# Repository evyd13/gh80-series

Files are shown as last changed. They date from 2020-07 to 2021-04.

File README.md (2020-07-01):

# GH80 series keyboard PCBs for Cherry boards

Please read the license before use. Each board has its own BOM and gerber files included.

These boards have been tested by numerous people, but I cannot guarantee that they work for your board.

I will not help you when you fuck up your soldering work, lol (though I might because I'm just too kind)

Oh by the way, use kicad nightly to open the source files.

## GH80-3000 vs GH80-3003
The 3000 is made by someone else, and the 3003 is mine. See it as my take on the same idea.

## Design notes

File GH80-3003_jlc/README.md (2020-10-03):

# GH80-3003 jlc

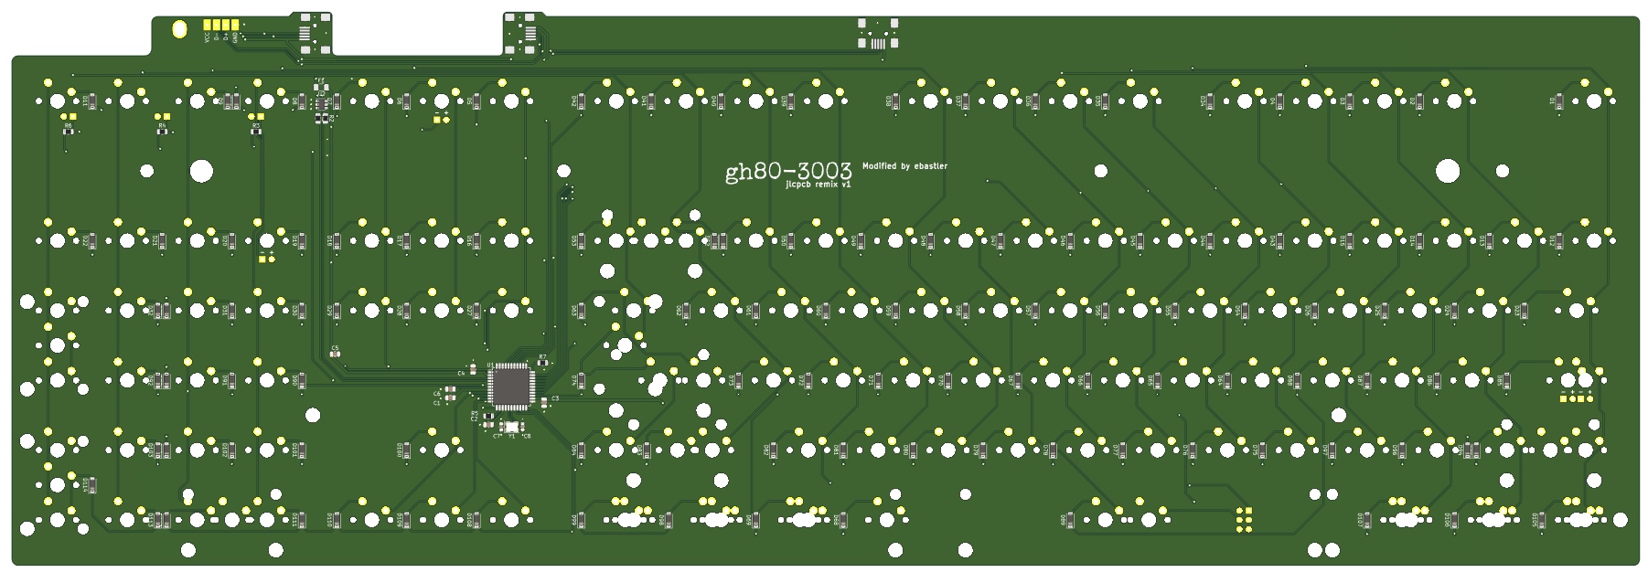
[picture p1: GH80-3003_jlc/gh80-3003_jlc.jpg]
GH80-3003 PCB


PCB designed by evyd13, edited to be assembled at jlcpcb by ebastler

Gerber, BOM and CPL file for jlcpcb assembly are included. They have been tested and confirmed working, but I can not guarantee that jlcpcb will not make any breaking changes. jlcpcb stocks might change, parts could go EOL. Compare MCU/diode/SRV05 rotation before ordering, to be sure.

If you order a small batch and sell the unneeded ones, please keep the license in mind.

## jlcpcb components (already in BOM/assembly files)

| Reference  | jlcpcb part # | Description | Value | Package  | Amount |
| --- | --- | --- | --- | --- | ---:|
| C1-C4 | C49678 | Capacitor | 0.1 uF | 0805 | 4 |
| C5 | C1779 | Capacitor | 4.7 uF | 0805 | 1 |
| C6 | C28323 | Capacitor | 1 uF | 0805 | 1 |
| C7, C8 | C1653 | Capacitor | 22 pF | 0603 | 2 |
| D1-D114 | C81598 | Diode | 1N4148 | SOD-123  | 114 |
| F1 | C183290 | Fuse | 750 mA | 1206 | 1 |
| R1, R2 | C17561 | Resistor | 22 | 0805 | 2 |
| R3, R4, R6 | C17513 | Resistor | 1 k | 0805 | 3 |
| R5, R6 | C17414 | Resistor | 10 k | 0805 | 2 |
| U1 | C44854 | MCU | 32U4 | QFP-44 | 1 |
| U2 | C85364 | ESD Protection | SRV-05 | SOT-23-6 | 1 |
| Y1 | C13738 | Crystal | 16 MHz | 3225-4 | 1 |

## Other parts
| Reference  | LCSC part # | Description | Value | Package  | Amount  |
| --- | --- | --- | --- | --- | ---:|
| K1-K114 | | Keyswitch | | MX-like  | depends |
| L1-L3 | | LED | | 3 mm THT | 3 |
| J2-J4 | C105424 | Connector | mini USB | SMD | 3 |
| SW1 | C92584 | Pushbutton | | SMD | 1 |

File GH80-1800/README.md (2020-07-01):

# GH80-1800

GH80-1800 PCB

## BOM

| LCSC part # | Description | Value | Package  | Amount |
| --- | --- | ----- | --- | ---:|
| C128353 | Capacitor | 0.1uF | 0805 | 4 |
| C131056 | Capacitor | 4.7uF | 0805 | 1 |
| C215803 | Capacitor | 1uF | 0805 | 1 |
| C109001 | Diode | | 0805 | 108 |
| C105424 | Connector | | SMD | 3 |
| C103904 | Resistor | 10K | 0805 | 2 |
| C384174 | Resistor | 1K | 0805 | 3 |
| C325772 | Resistor | 22 | 0805 | 2 |
| C44854 | MCU | 32U4  | QFP-44 | 1 |
| C341521 | Resonator | 16MHz | SMD | 1 |
| C92584 | Switch | | SMD | 1 |

Use at your own risk.

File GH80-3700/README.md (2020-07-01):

# GH80-3700

GH80-3700 PCB

## BOM main pcb

| LCSC part # | Description | Value | Package  | Amount |
| --- | --- | ----- | --- | ---:|
| C128353 | Capacitor | 0.1uF | 0805 | 4 |
| C131056 | Capacitor | 4.7uF | 0805 | 1 |
| C215803 | Capacitor | 1uF | 0805 | 1 |
| C109001 | Diode | | 0805 | 24 |
| C165948 | Connector | | SMD/THT  | 1 |
| C103904 | Resistor | 10K | 0805 | 2 |
| C212411 | Resistor | 5.1K  | 0805 | 2 |
| C384174 | Resistor | 1K | 0805 | 5 |
| C325772 | Resistor | 22 | 0805 | 2 |
| C44854 | MCU | 32U4  | QFP-44 | 1 |
| C7519 | ESD chip | | SOT23-6  | 1 |
| C261942 | Fuse | | 0805 | 1 |
| C341521 | Resonator | 16MHz | SMD | 1 |
| C223806 | Switch | | THT | 1 |

## BOM daughterboard (speaker and ps/2 port) pcb

It's a little expansion board to be able to use a speaker or PS/2 mouse, or just to fill up that hole in the case.

| LCSC part # | Description | Value | Package  | Amount |
| --- | --- | ----- | --- | ---:|
| C131056 | Capacitor | 4.7uF | 0805 | 1 |
| C17673 | Resistor | 4.7K  | 0805 | 2 |
| C261942 | Fuse | | 0805 | 1 |
| C136657 | JST SH 5 pin  | | SMD | 2 |
|  C77848 | PS2 connector | | THT | 1 |

You'll also need a JST SH 5 pin cable for this one. Those can be found on aliexpress or similar sites.

Use at your own risk.

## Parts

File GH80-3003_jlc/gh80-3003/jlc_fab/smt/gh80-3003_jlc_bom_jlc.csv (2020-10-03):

Comment | Designator | Footprint | LCSC Part #
0.1u | C1,C2,C3,C4 | C_0805_2012Metric | C49678
4.7u | C5 | C_0805_2012Metric | C1779
1u | C6 | C_0805_2012Metric | C28323
22p | C7,C8 | C_0603_1608Metric | C1653
1N4148 | D1,D2,D3,D4,D5,D6,D7,D8,D9,D10,D11,D12,D13,D14,D15,D16,D17,D18,D19,D20,D21,D22,D23,D24,D25,D26,D27,D28,D29,D30,D31,D32,D33,D34,D35,D36,D37,D38,D39,D40,D41,D42,D43,D44,D45,D46,D47,D48,D49,D50,D51,D52,D53,D54,D55,D56,D57,D58,D59,D60,D61,D62,D63,D64,D65,D66,D67,D68,D69,D70,D71,D72,D73,D74,D75,D76,D77,D78,D79,D80,D81,D82,D83,D84,D85,D86,D87,D88,D89,D90,D91,D92,D93,D94,D95,D96,D97,D98,D99,D100,D101,D102,D103,D104,D105,D106,D107,D108,D109,D110,D111,D112,D113,D114 | D_SOD-123 | C81598
Fuse | F1 | Fuse_1206_3216Metric | C183290
22 | R1,R2 | R_0805_2012Metric | C17561
1k | R3,R4,R6 | R_0805_2012Metric | C17513
10k | R5,R7 | R_0805_2012Metric | C17414
ATmega32U4 | U1 | TQFP-44_10x10mm_P0.8mm | C44854
SRV05-4 | U2 | SOT-23-6 | C85364
Crystal_GND24_Small | Y1 | Crystal_SMD_3225-4Pin_3.2x2.5mm | C13738

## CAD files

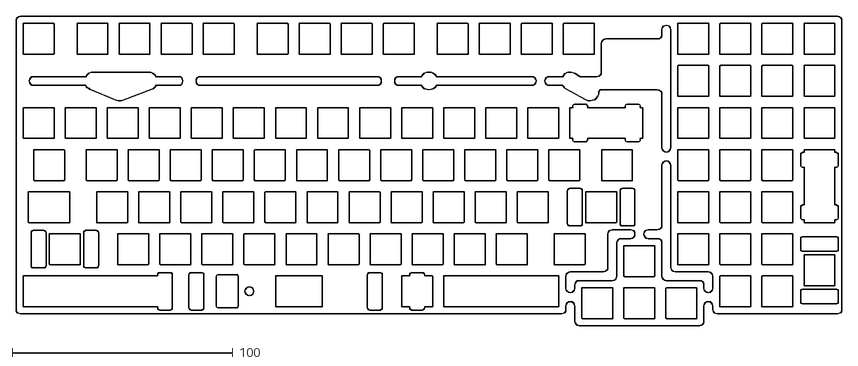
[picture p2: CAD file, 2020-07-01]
GH80-1800/plate/gh80_1800_ANSI.dxf
374.0 x 140.1

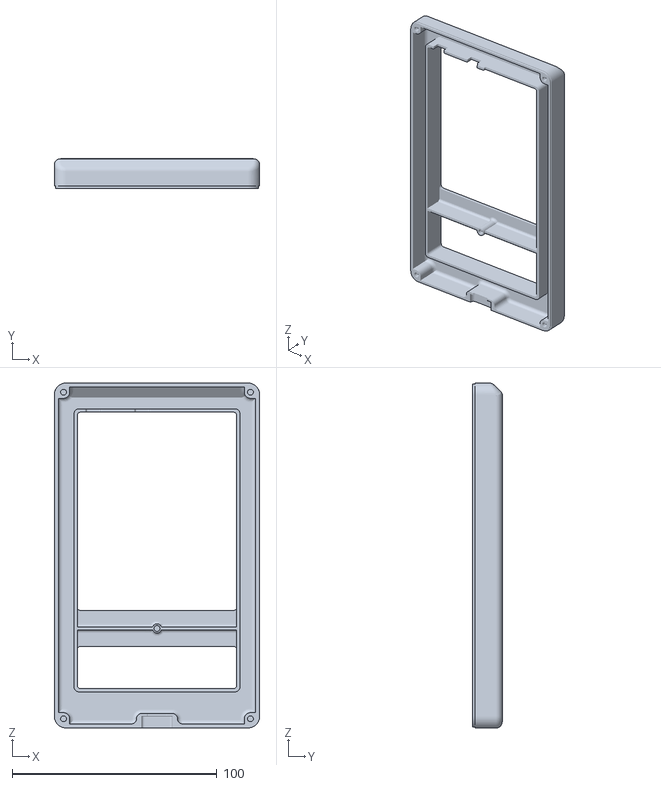
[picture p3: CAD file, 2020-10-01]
GH80-3700/case/top.stl
100.2 x 14.4 x 168.4

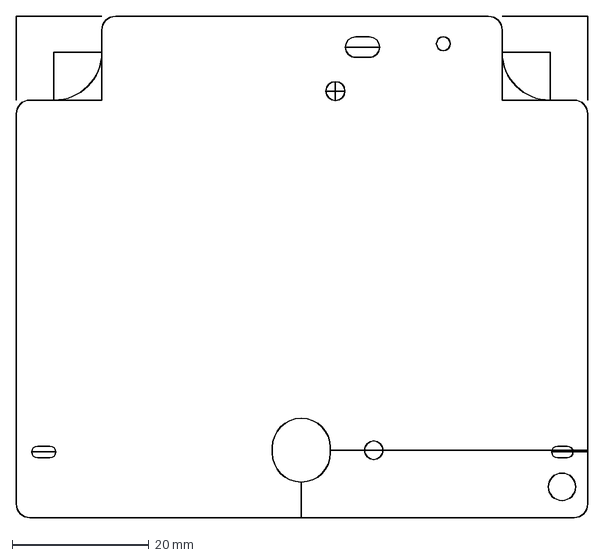
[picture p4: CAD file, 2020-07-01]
GH80-3700/daughterboard/pcb.dxf
83.5 x 73.3 mm

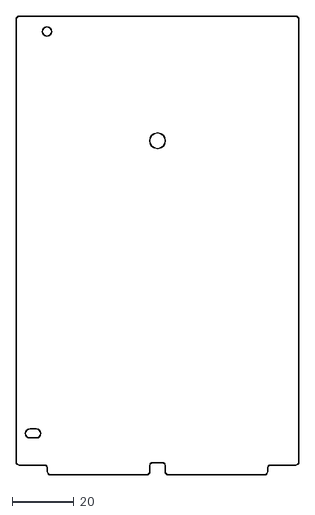
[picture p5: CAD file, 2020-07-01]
GH80-3700/PCB/pcb.dxf
91.8 x 149.1

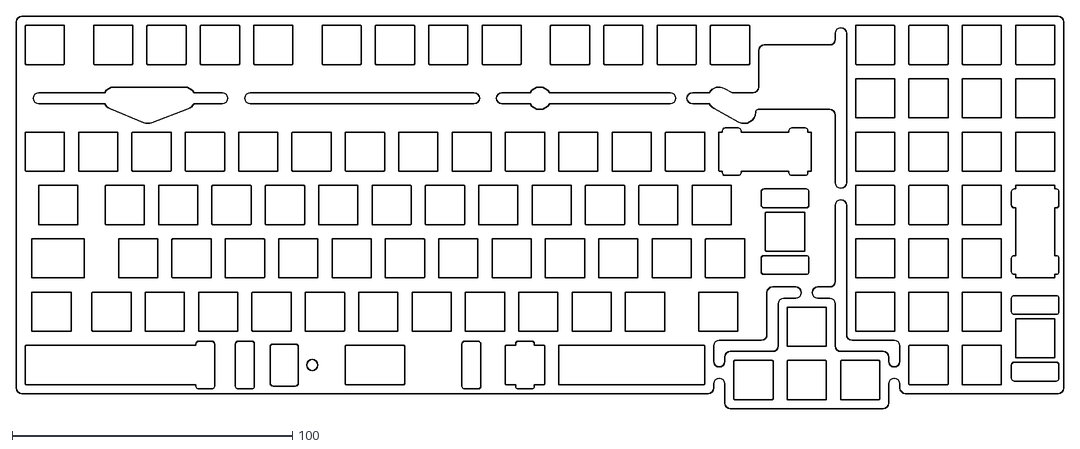
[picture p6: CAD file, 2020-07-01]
GH80-1800/plate/gh80_1800_ISO.dxf
374.0 x 140.1

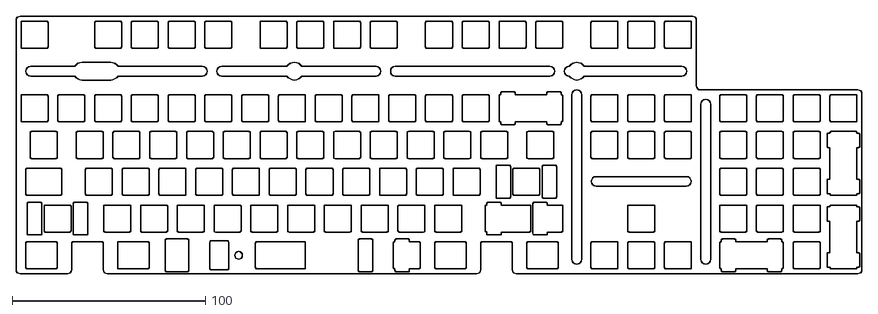
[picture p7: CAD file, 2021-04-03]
GH80-3003/plate/gh80-3003-ansi.dxf
438.2 x 133.4

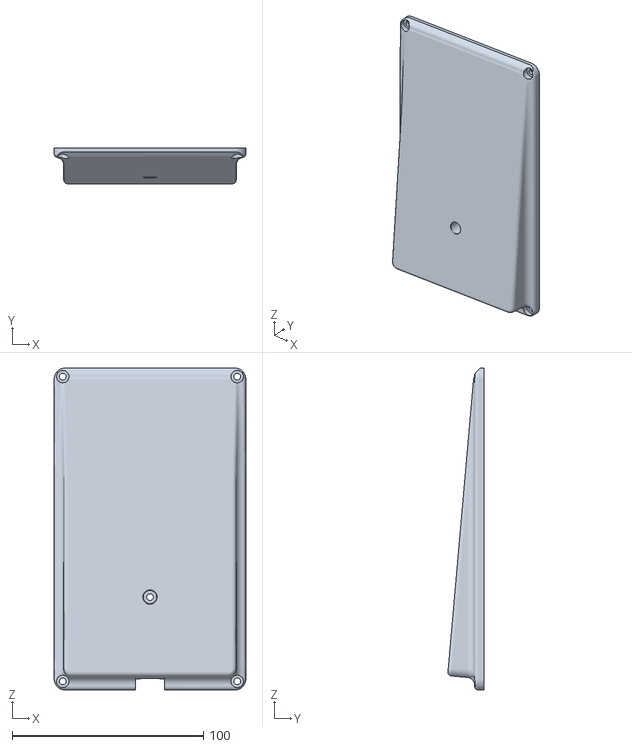
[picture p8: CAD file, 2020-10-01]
GH80-3700/case/bottom.stl
100.2 x 18.9 x 168.4

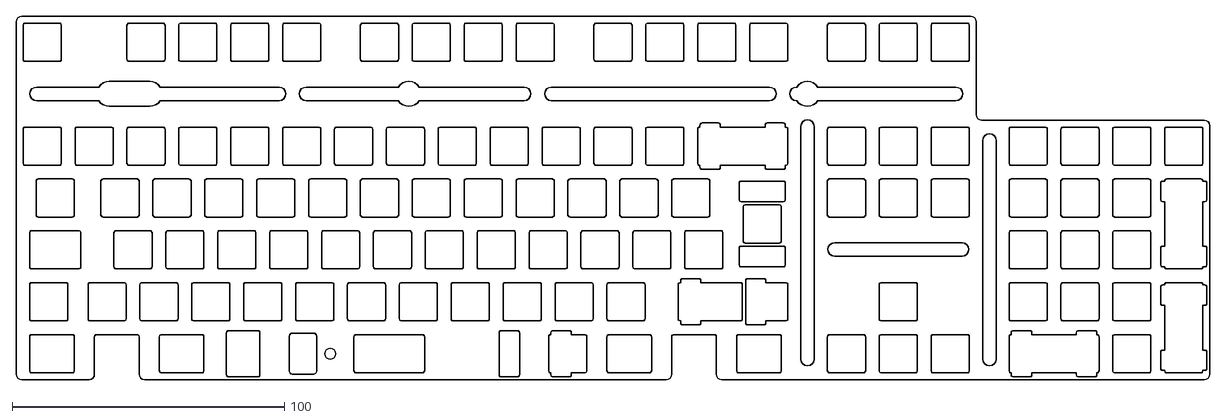
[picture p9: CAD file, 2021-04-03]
GH80-3003/plate/gh80-3003-iso.dxf
438.2 x 133.4

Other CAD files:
GH80-3003/plate/plate.FCStd
GH80-3700/plate/G80-3700.FCStd
GH80-1800/plate/gh80_1800.FCStd
GH80-3700/case/case.f3z
GH80-3700/plate/G80-3700.dxf

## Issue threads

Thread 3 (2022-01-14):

1800 in kicad does not seem to open properly

alinelena, 2022-01-14:
I am opening 1800 in kicad but seems does not open quite right.
https://i.imgur.com/adBBMC9.png
if I click on them footprints are not there.

supplied gerbers or generated gerbers do not seem to load on jlcpcb either.

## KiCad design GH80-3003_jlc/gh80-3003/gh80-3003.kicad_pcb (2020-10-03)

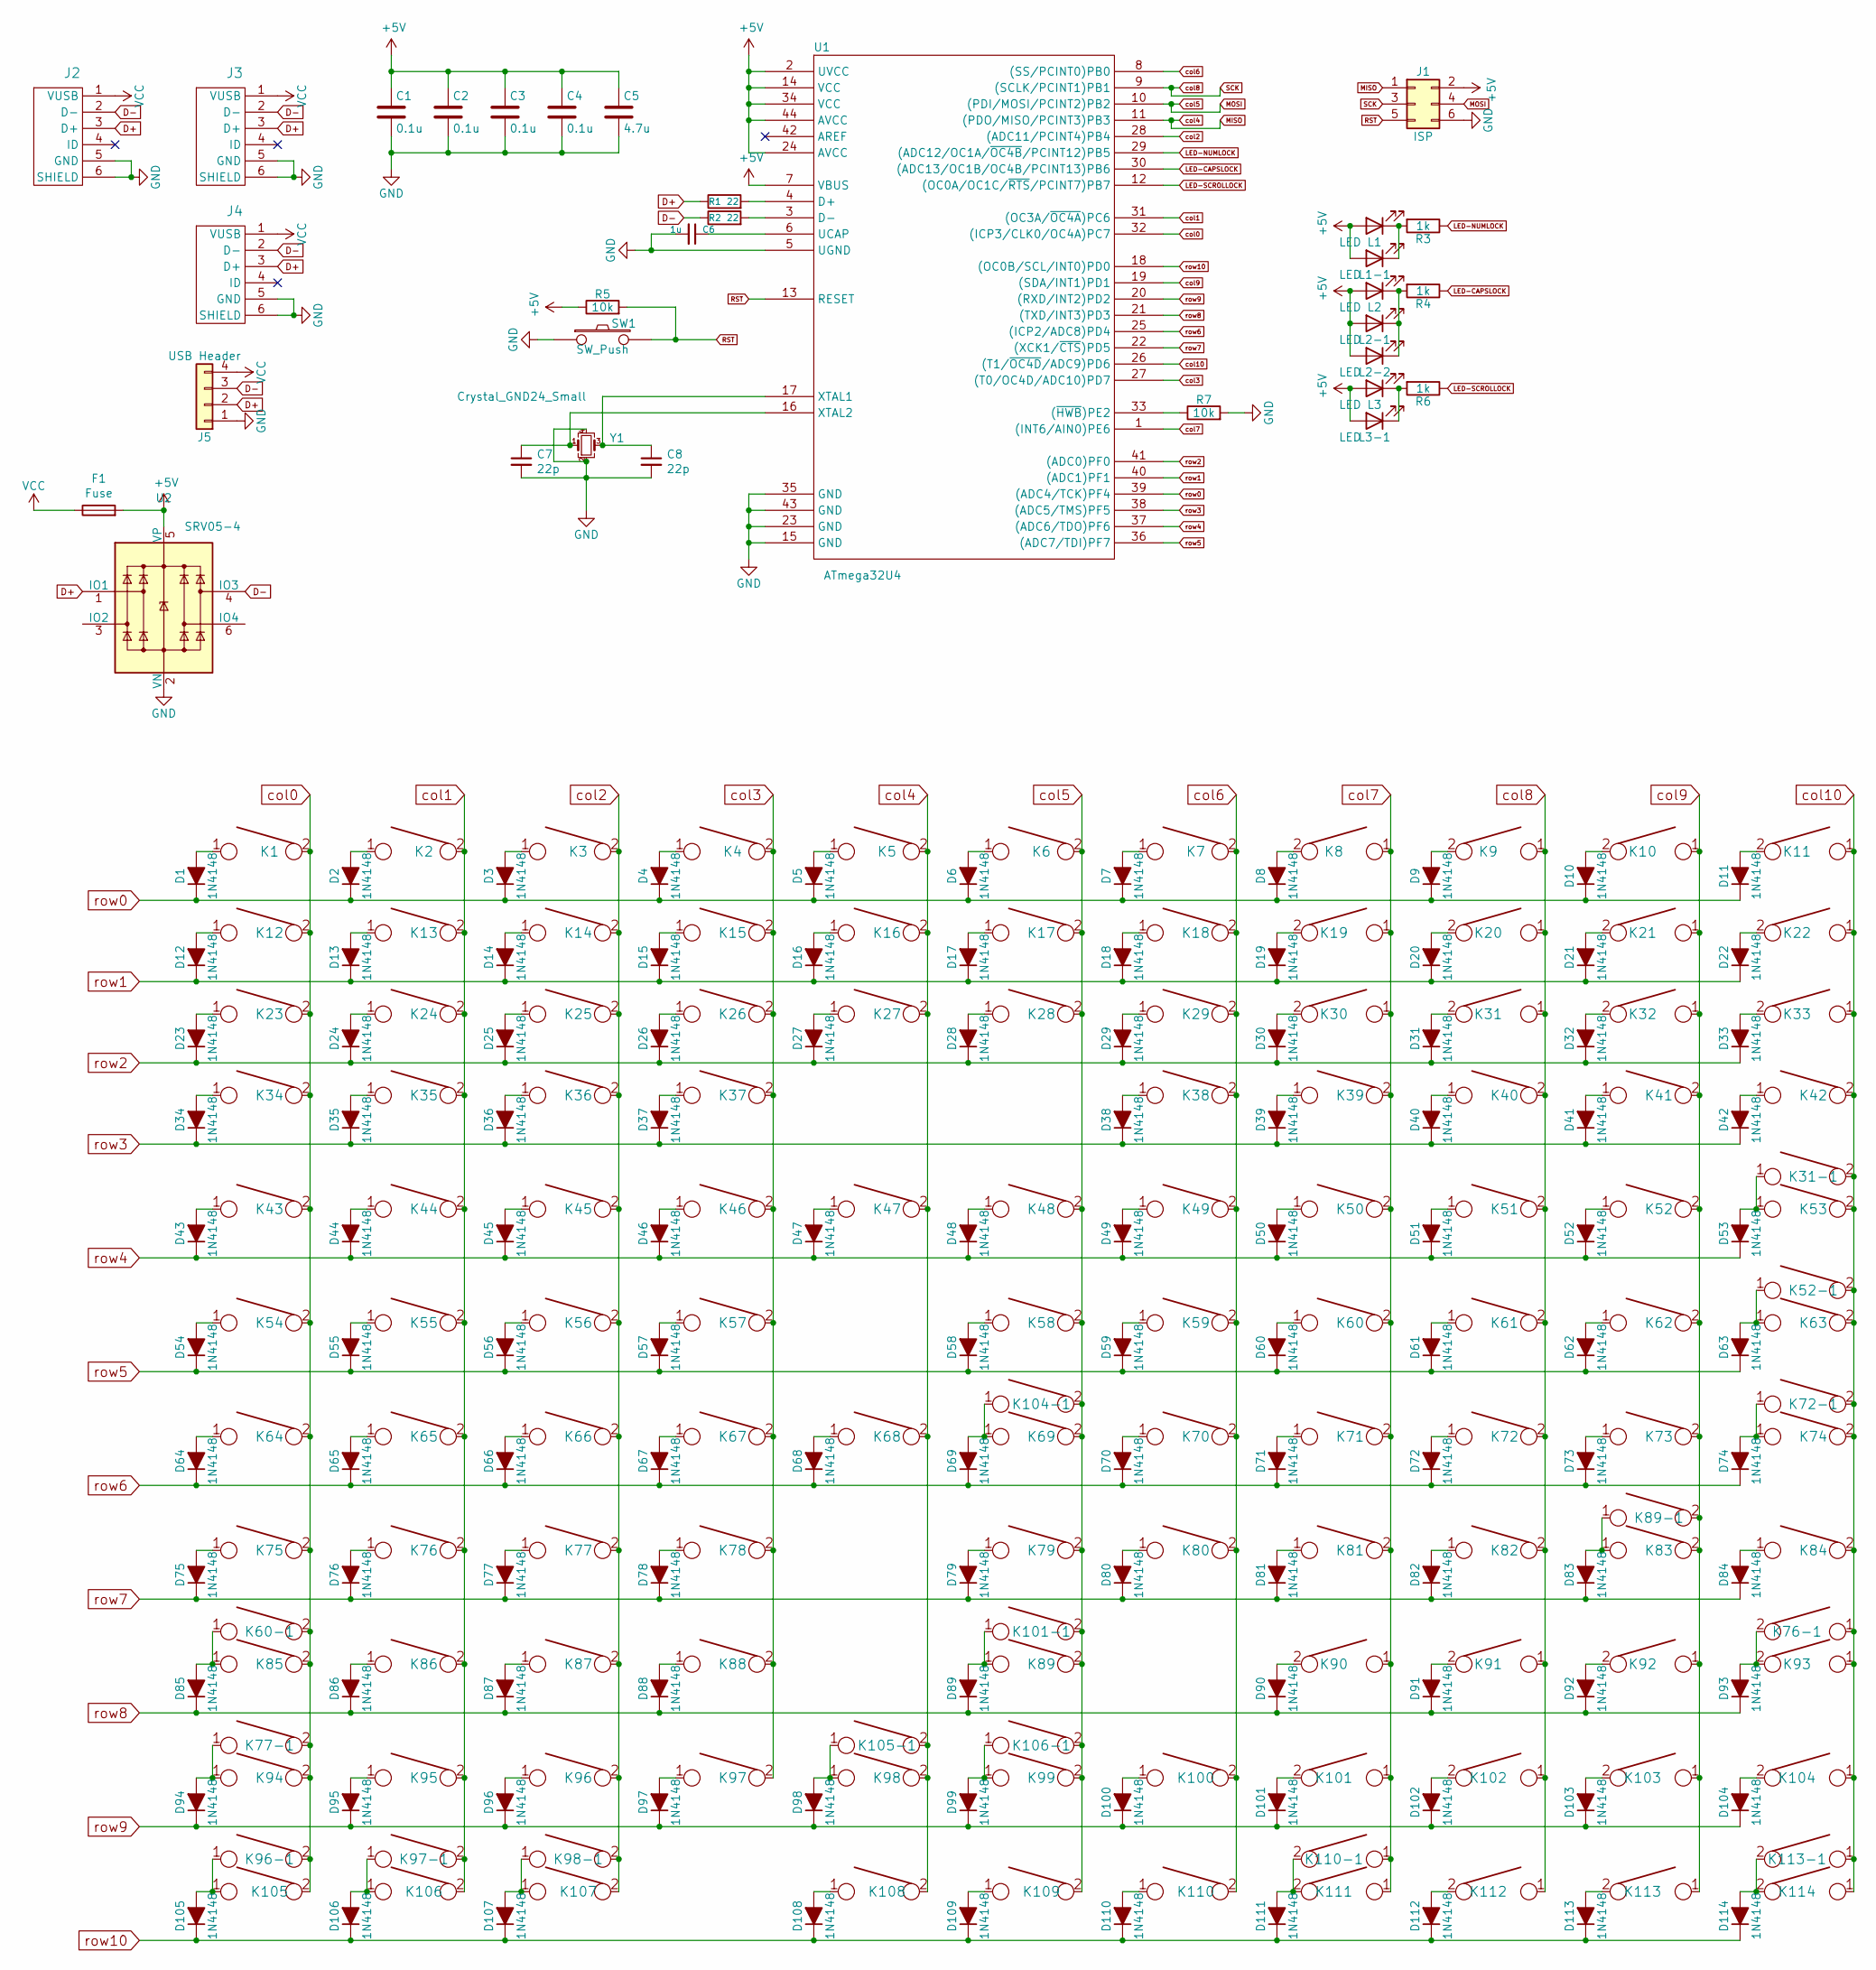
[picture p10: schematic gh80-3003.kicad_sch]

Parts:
C1, C2, C3, C4: 0.1u; C_0805_2012Metric; LCSC C49678
C5: 4.7u; C_0805_2012Metric; LCSC C1779
C6: 1u; C_0805_2012Metric; LCSC C28323
C7, C8: 22p; C_0603_1608Metric; LCSC C1653
D1, D2, D3, D4, D5, D6, D7, D8, D9, D10, D11, D12, D13, D14, D15, D16, D17, D18, D19, D20, D21, D22, D23, D24, D25, D26, D27, D28, D29, D30, D31, D32, D33, D34, D35, D36, D37, D38, D39, D40, D41, D42, D43, D44, D45, D46, D47, D48, D49, D50, D51, D52, D53, D54, D55, D56, D57, D58, D59, D60, D61, D62, D63, D64, D65, D66, D67, D68, D69, D70, D71, D72, D73, D74, D75, D76, D77, D78, D79, D80, D81, D82, D83, D84, D85, D86, D87, D88, D89, D90, D91, D92, D93, D94, D95, D96, D97, D98, D99, D100, D101, D102, D103, D104, D105, D106, D107, D108, D109, D110, D111, D112, D113, D114: 1N4148; D_SOD-123; LCSC C81598
F1: Fuse; Fuse_1206_3216Metric; LCSC C183290
J1: ISP; isp_standard
J2, J3, J4: USB_mini_micro_B; USB_Mini_SMD
J5: USB Header; USB_breakout
K1, K2, K3, K4, K5, K6, K7, K8, K9, K10, K11, K12, K13, K14, K15, K16, K17, K18, K19, K20, K21, K22, K24, K25, K26, K27, K28, K29, K30, K31, K31-1, K32, K33, K34, K35, K36, K37, K38, K39, K40, K41, K42, K43, K44, K45, K46, K47, K48, K49, K50, K51, K52, K52-1, K54, K55, K56, K57, K58, K59, K60, K61, K62, K64, K65, K66, K67, K70, K71, K72, K73, K75, K76, K76-1, K77, K78, K79, K80, K81, K82, K84, K86, K87, K88, K90, K91, K92, K95, K96, K97, K98, K100, K101, K102, K103, K104, K106, K108, K109, K110, K110-1, K112, K113, K113-1: KEYSW; CHERRY_PLATE_100H
K23, K63, K69, K99, K105, K107: KEYSW; CHERRY_PLATE_150H
K53, K111: KEYSW; CHERRY_PCB_200H
K60-1, K68, K77-1, K96-1, K97-1, K98-1, K104-1, K105-1, K106-1: KEYSW; CHERRY_PLATE_125H
K72-1: KEYSW; CHERRY_PCB_200H_V
K74, K94: KEYSW; CHERRY_PCB_225H
K83: KEYSW; CHERRY_PCB_275H
K85, K89-1: KEYSW; CHERRY_PLATE_175H
K89: KEYSW; CHERRY_PCB_700H
K93, K114: KEYSW; CHERRY_PCB_200H_V_F
K101-1: KEYSW; CHERRY_PCB_625H
L1, L2, L3: LED; LED_D3.0mm
L1-1, L2-1, L2-2, L3-1: LED; CHERRY_MX_LED
R1, R2: 22; R_0805_2012Metric; LCSC C17561
R3, R4, R6: 1k; R_0805_2012Metric; LCSC C17513
R5, R7: 10k; R_0805_2012Metric; LCSC C17414
SW1: SW_Push; SW_SPST_TL3342
U1: ATmega32U4; TQFP-44_10x10mm_P0.8mm; LCSC C44854
U2: SRV05-4; SOT-23-6; LCSC C85364
Y1: Crystal_GND24_Small; Crystal_SMD_3225-4Pin_3.2x2.5mm; LCSC C13738

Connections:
+5V: C1.1, C2.1, C3.1, C4.1, C5.1, F1.2, J1.2, L1.2 (A), L1-1.2 (A), L2.2 (A), L2-1.2 (A), L2-2.2 (A), L3.2 (A), L3-1.2 (A), R5.1, U1.2 (UVCC), U1.7 (VBUS), U1.14 (VCC), U1.24 (AVCC), U1.34 (VCC), U1.44 (AVCC), U2.5 (VP)
D+: J2.3 (D+), J3.3 (D+), J4.3 (D+), J5.2, R1.1, U2.1 (IO1)
D-: J2.2 (D-), J3.2 (D-), J4.2 (D-), J5.3, R2.1, U2.4 (IO3)
GND: C1.2, C2.2, C3.2, C4.2, C5.2, C6.2, C7.2, C8.2, J1.6, J2.5 (GND), J2.6 (SHIELD), J3.5 (GND), J3.6 (SHIELD), J4.5 (GND), J4.6 (SHIELD), J5.1, R7.2, SW1.1, U1.5 (UGND), U1.15 (GND), U1.23 (GND), U1.35 (GND), U1.43 (GND), U2.2 (VN), Y1.2, Y1.4
LED-CAPSLOCK: R4.1, U1.30 ((ADC13/OC1B/OC4B/PCINT13)PB6)
LED-NUMLOCK: R3.1, U1.29 ((ADC12/OC1A/~OC4B~/PCINT12)PB5)
LED-SCROLLOCK: R6.1, U1.12 ((OC0A/OC1C/~RTS~/PCINT7)PB7)
MISO: J1.1, K5.2, K16.2, K27.2, K47.2, K68.2, K98.2, K105-1.2, K108.2, U1.11 ((PDO/MISO/PCINT3)PB3)
MOSI: J1.4, K6.2, K17.2, K28.2, K48.2, K58.2, K69.2, K79.2, K89.2, K99.2, K101-1.2, K104-1.2, K106-1.2, K109.2, U1.10 ((PDI/MOSI/PCINT2)PB2)
unnamed: C6.1, U1.6 (UCAP)
unnamed: C7.1, U1.16 (XTAL2), Y1.1
unnamed: C8.1, U1.17 (XTAL1), Y1.3
unnamed: D1.2 (A), K1.1
unnamed: D2.2 (A), K2.1
unnamed: D3.2 (A), K3.1
unnamed: D4.2 (A), K4.1
unnamed: D5.2 (A), K5.1
unnamed: D6.2 (A), K6.1
unnamed: D7.2 (A), K7.1
unnamed: D8.2 (A), K8.2
unnamed: D9.2 (A), K9.2
unnamed: D10.2 (A), K10.2
unnamed: D11.2 (A), K11.2
unnamed: D12.2 (A), K12.1
unnamed: D13.2 (A), K13.1
unnamed: D14.2 (A), K14.1
unnamed: D15.2 (A), K15.1
unnamed: D16.2 (A), K16.1
unnamed: D17.2 (A), K17.1
unnamed: D18.2 (A), K18.1
unnamed: D19.2 (A), K19.2
unnamed: D20.2 (A), K20.2
unnamed: D21.2 (A), K21.2
unnamed: D22.2 (A), K22.2
unnamed: D23.2 (A), K23.1
unnamed: D24.2 (A), K24.1
unnamed: D25.2 (A), K25.1
unnamed: D26.2 (A), K26.1
unnamed: D27.2 (A), K27.1
unnamed: D28.2 (A), K28.1
unnamed: D29.2 (A), K29.1
unnamed: D30.2 (A), K30.2
unnamed: D31.2 (A), K31.2
unnamed: D32.2 (A), K32.2
unnamed: D33.2 (A), K33.2
unnamed: D34.2 (A), K34.1
unnamed: D35.2 (A), K35.1
unnamed: D36.2 (A), K36.1
unnamed: D37.2 (A), K37.1
unnamed: D38.2 (A), K38.1
unnamed: D39.2 (A), K39.1
unnamed: D40.2 (A), K40.1
unnamed: D41.2 (A), K41.1
unnamed: D42.2 (A), K42.1
unnamed: D43.2 (A), K43.1
unnamed: D44.2 (A), K44.1
unnamed: D45.2 (A), K45.1
unnamed: D46.2 (A), K46.1
unnamed: D47.2 (A), K47.1
unnamed: D48.2 (A), K48.1
unnamed: D49.2 (A), K49.1
unnamed: D50.2 (A), K50.1
unnamed: D51.2 (A), K51.1
unnamed: D52.2 (A), K52.1
unnamed: D53.2 (A), K31-1.1, K53.1
unnamed: D54.2 (A), K54.1
unnamed: D55.2 (A), K55.1
unnamed: D56.2 (A), K56.1
unnamed: D57.2 (A), K57.1
unnamed: D58.2 (A), K58.1
unnamed: D59.2 (A), K59.1
unnamed: D60.2 (A), K60.1
unnamed: D61.2 (A), K61.1
unnamed: D62.2 (A), K62.1
unnamed: D63.2 (A), K52-1.1, K63.1
unnamed: D64.2 (A), K64.1
unnamed: D65.2 (A), K65.1
unnamed: D66.2 (A), K66.1
unnamed: D67.2 (A), K67.1
unnamed: D68.2 (A), K68.1
unnamed: D69.2 (A), K69.1, K104-1.1
unnamed: D70.2 (A), K70.1
unnamed: D71.2 (A), K71.1
unnamed: D72.2 (A), K72.1
unnamed: D73.2 (A), K73.1
unnamed: D74.2 (A), K72-1.1, K74.1
unnamed: D75.2 (A), K75.1
unnamed: D76.2 (A), K76.1
unnamed: D77.2 (A), K77.1
unnamed: D78.2 (A), K78.1
unnamed: D79.2 (A), K79.1
unnamed: D80.2 (A), K80.1
unnamed: D81.2 (A), K81.1
unnamed: D82.2 (A), K82.1
unnamed: D83.2 (A), K83.1, K89-1.1
unnamed: D84.2 (A), K84.1
unnamed: D85.2 (A), K60-1.1, K85.1
unnamed: D86.2 (A), K86.1
unnamed: D87.2 (A), K87.1
unnamed: D88.2 (A), K88.1
unnamed: D89.2 (A), K89.1, K101-1.1
unnamed: D90.2 (A), K90.2
unnamed: D91.2 (A), K91.2
unnamed: D92.2 (A), K92.2
unnamed: D93.2 (A), K76-1.2, K93.2
unnamed: D94.2 (A), K77-1.1, K94.1
unnamed: D95.2 (A), K95.1
unnamed: D96.2 (A), K96.1
unnamed: D97.2 (A), K97.1
unnamed: D98.2 (A), K98.1, K105-1.1
unnamed: D99.2 (A), K99.1, K106-1.1
unnamed: D100.2 (A), K100.1
unnamed: D101.2 (A), K101.2
unnamed: D102.2 (A), K102.2
unnamed: D103.2 (A), K103.2
unnamed: D104.2 (A), K104.2
unnamed: D105.2 (A), K96-1.1, K105.1
unnamed: D106.2 (A), K97-1.1, K106.1
unnamed: D107.2 (A), K98-1.1, K107.1
unnamed: D108.2 (A), K108.1
unnamed: D109.2 (A), K109.1
unnamed: D110.2 (A), K110.1
unnamed: D111.2 (A), K110-1.2, K111.2
unnamed: D112.2 (A), K112.2
unnamed: D113.2 (A), K113.2
unnamed: D114.2 (A), K113-1.2, K114.2
unnamed: L1.1 (K), L1-1.1 (K), R3.2
unnamed: L2.1 (K), L2-1.1 (K), L2-2.1 (K), R4.2
unnamed: L3.1 (K), L3-1.1 (K), R6.2
unnamed: R1.2, U1.4 (D+)
unnamed: R2.2, U1.3 (D-)
unnamed: R7.1, U1.33 ((~HWB~)PE2)
RST: J1.5, R5.2, SW1.2, U1.13 (RESET)
SCK: J1.3, K9.1, K20.1, K31.1, K40.2, K51.2, K61.2, K72.2, K82.2, K91.1, K102.1, K112.1, U1.9 ((SCLK/PCINT1)PB1)
VCC: F1.1, J2.1 (VUSB), J3.1 (VUSB), J4.1 (VUSB), J5.4
col0: K1.2, K12.2, K23.2, K34.2, K43.2, K54.2, K60-1.2, K64.2, K75.2, K77-1.2, K85.2, K94.2, K96-1.2, K105.2, U1.32 ((ICP3/CLK0/OC4A)PC7)
col1: K2.2, K13.2, K24.2, K35.2, K44.2, K55.2, K65.2, K76.2, K86.2, K95.2, K97-1.2, K106.2, U1.31 ((OC3A/~OC4A~)PC6)
col2: K3.2, K14.2, K25.2, K36.2, K45.2, K56.2, K66.2, K77.2, K87.2, K96.2, K98-1.2, K107.2, U1.28 ((ADC11/PCINT4)PB4)
col3: K4.2, K15.2, K26.2, K37.2, K46.2, K57.2, K67.2, K78.2, K88.2, K97.2, U1.27 ((T0/OC4D/ADC10)PD7)
col6: K7.2, K18.2, K29.2, K38.2, K49.2, K59.2, K70.2, K80.2, K100.2, K110.2, U1.8 ((SS/PCINT0)PB0)
col7: K8.1, K19.1, K30.1, K39.2, K50.2, K60.2, K71.2, K81.2, K90.1, K101.1, K110-1.1, K111.1, U1.1 ((INT6/AIN0)PE6)
col9: K10.1, K21.1, K32.1, K41.2, K52.2, K62.2, K73.2, K83.2, K89-1.2, K92.1, K103.1, K113.1, U1.19 ((SDA/INT1)PD1)
col10: K11.1, K22.1, K31-1.2, K33.1, K42.2, K52-1.2, K53.2, K63.2, K72-1.2, K74.2, K76-1.1, K84.2, K93.1, K104.1, K113-1.1, K114.1, U1.26 ((T1/~OC4D~/ADC9)PD6)
row0: D1.1 (K), D2.1 (K), D3.1 (K), D4.1 (K), D5.1 (K), D6.1 (K), D7.1 (K), D8.1 (K), D9.1 (K), D10.1 (K), D11.1 (K), U1.39 ((ADC4/TCK)PF4)
row1: D12.1 (K), D13.1 (K), D14.1 (K), D15.1 (K), D16.1 (K), D17.1 (K), D18.1 (K), D19.1 (K), D20.1 (K), D21.1 (K), D22.1 (K), U1.40 ((ADC1)PF1)
row2: D23.1 (K), D24.1 (K), D25.1 (K), D26.1 (K), D27.1 (K), D28.1 (K), D29.1 (K), D30.1 (K), D31.1 (K), D32.1 (K), D33.1 (K), U1.41 ((ADC0)PF0)
row3: D34.1 (K), D35.1 (K), D36.1 (K), D37.1 (K), D38.1 (K), D39.1 (K), D40.1 (K), D41.1 (K), D42.1 (K), U1.38 ((ADC5/TMS)PF5)
row4: D43.1 (K), D44.1 (K), D45.1 (K), D46.1 (K), D47.1 (K), D48.1 (K), D49.1 (K), D50.1 (K), D51.1 (K), D52.1 (K), D53.1 (K), U1.37 ((ADC6/TDO)PF6)
row5: D54.1 (K), D55.1 (K), D56.1 (K), D57.1 (K), D58.1 (K), D59.1 (K), D60.1 (K), D61.1 (K), D62.1 (K), D63.1 (K), U1.36 ((ADC7/TDI)PF7)
row6: D64.1 (K), D65.1 (K), D66.1 (K), D67.1 (K), D68.1 (K), D69.1 (K), D70.1 (K), D71.1 (K), D72.1 (K), D73.1 (K), D74.1 (K), U1.25 ((ICP2/ADC8)PD4)
row7: D75.1 (K), D76.1 (K), D77.1 (K), D78.1 (K), D79.1 (K), D80.1 (K), D81.1 (K), D82.1 (K), D83.1 (K), D84.1 (K), U1.22 ((XCK1/~CTS~)PD5)
row8: D85.1 (K), D86.1 (K), D87.1 (K), D88.1 (K), D89.1 (K), D90.1 (K), D91.1 (K), D92.1 (K), D93.1 (K), U1.21 ((TXD/INT3)PD3)
row9: D94.1 (K), D95.1 (K), D96.1 (K), D97.1 (K), D98.1 (K), D99.1 (K), D100.1 (K), D101.1 (K), D102.1 (K), D103.1 (K), D104.1 (K), U1.20 ((RXD/INT2)PD2)
row10: D105.1 (K), D106.1 (K), D107.1 (K), D108.1 (K), D109.1 (K), D110.1 (K), D111.1 (K), D112.1 (K), D113.1 (K), D114.1 (K), U1.18 ((OC0B/SCL/INT0)PD0)

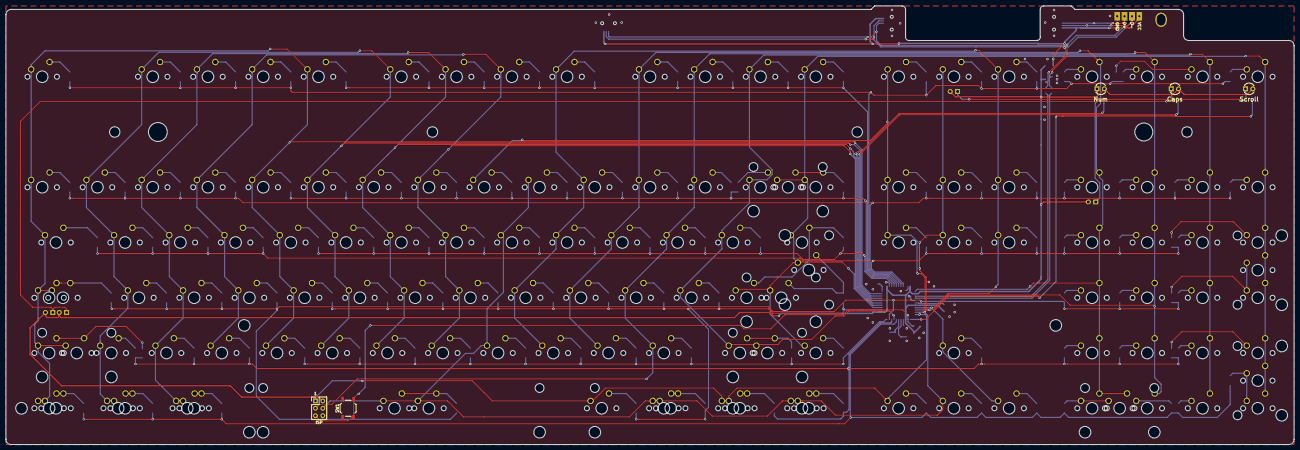
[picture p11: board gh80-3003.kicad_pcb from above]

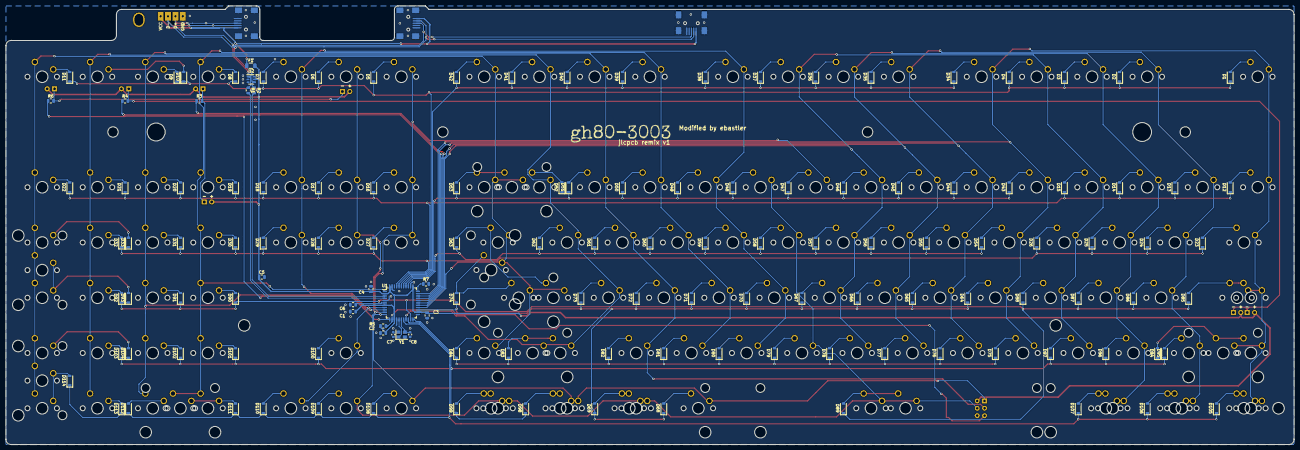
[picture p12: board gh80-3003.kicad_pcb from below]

Board: 2 copper layers, 444.1 x 151.2 mm, 276 parts (136 on the bottom side), 154 nets.

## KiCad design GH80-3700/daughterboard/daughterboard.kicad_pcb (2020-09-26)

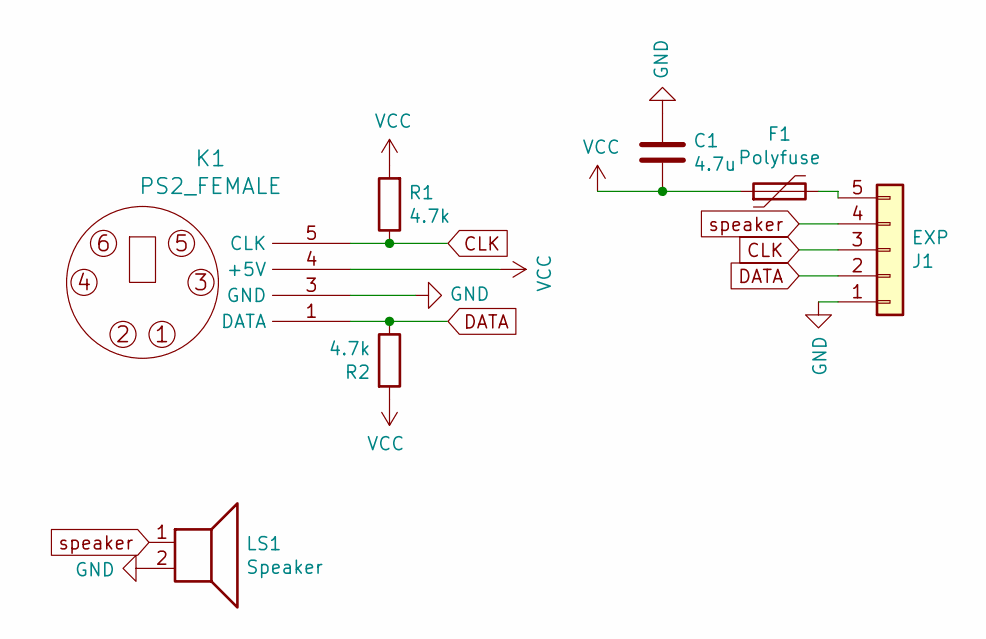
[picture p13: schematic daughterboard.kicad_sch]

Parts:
C1: 4.7u; C_0805
F1: Polyfuse; R_0805
J1: EXP; JST_SH_SM05B-SRSS-TB_1x05-1MP_P1.00mm_Horizontal
K1: PS2_FEMALE; ps2_connector
LS1: Speaker; speaker_AST1109MLTRQ
R1, R2: 4.7k; R_0805

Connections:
CLK: J1.3, K1.5 (CLK), R1.1
DATA: J1.2, K1.1 (DATA), R2.1
GND: C1.2, J1.1, K1.3 (GND), LS1.2
unnamed: F1.2, J1.5
VCC: C1.1, F1.1, K1.4 (+5V), R1.2, R2.2
speaker: J1.4, LS1.1

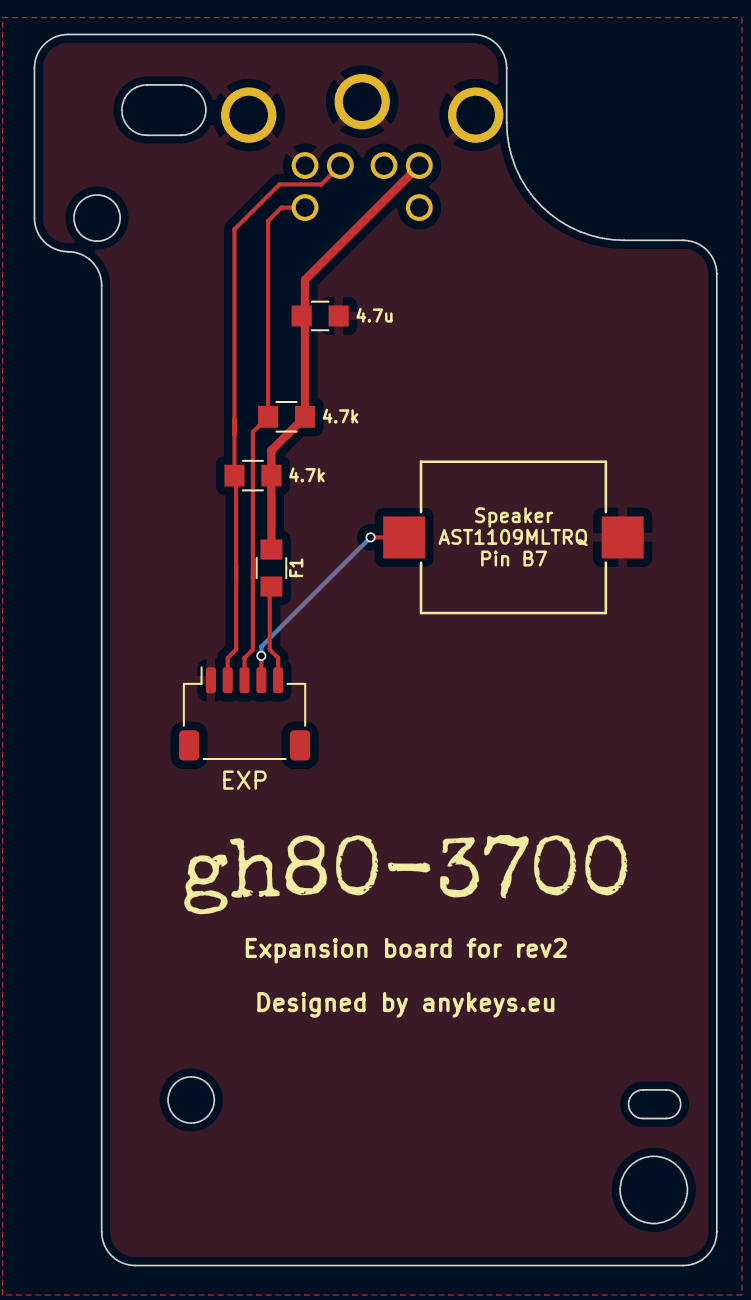
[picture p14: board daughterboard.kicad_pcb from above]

Board: 2 copper layers, 40.6 x 73.2 mm, 7 parts (0 on the bottom side), 6 nets.

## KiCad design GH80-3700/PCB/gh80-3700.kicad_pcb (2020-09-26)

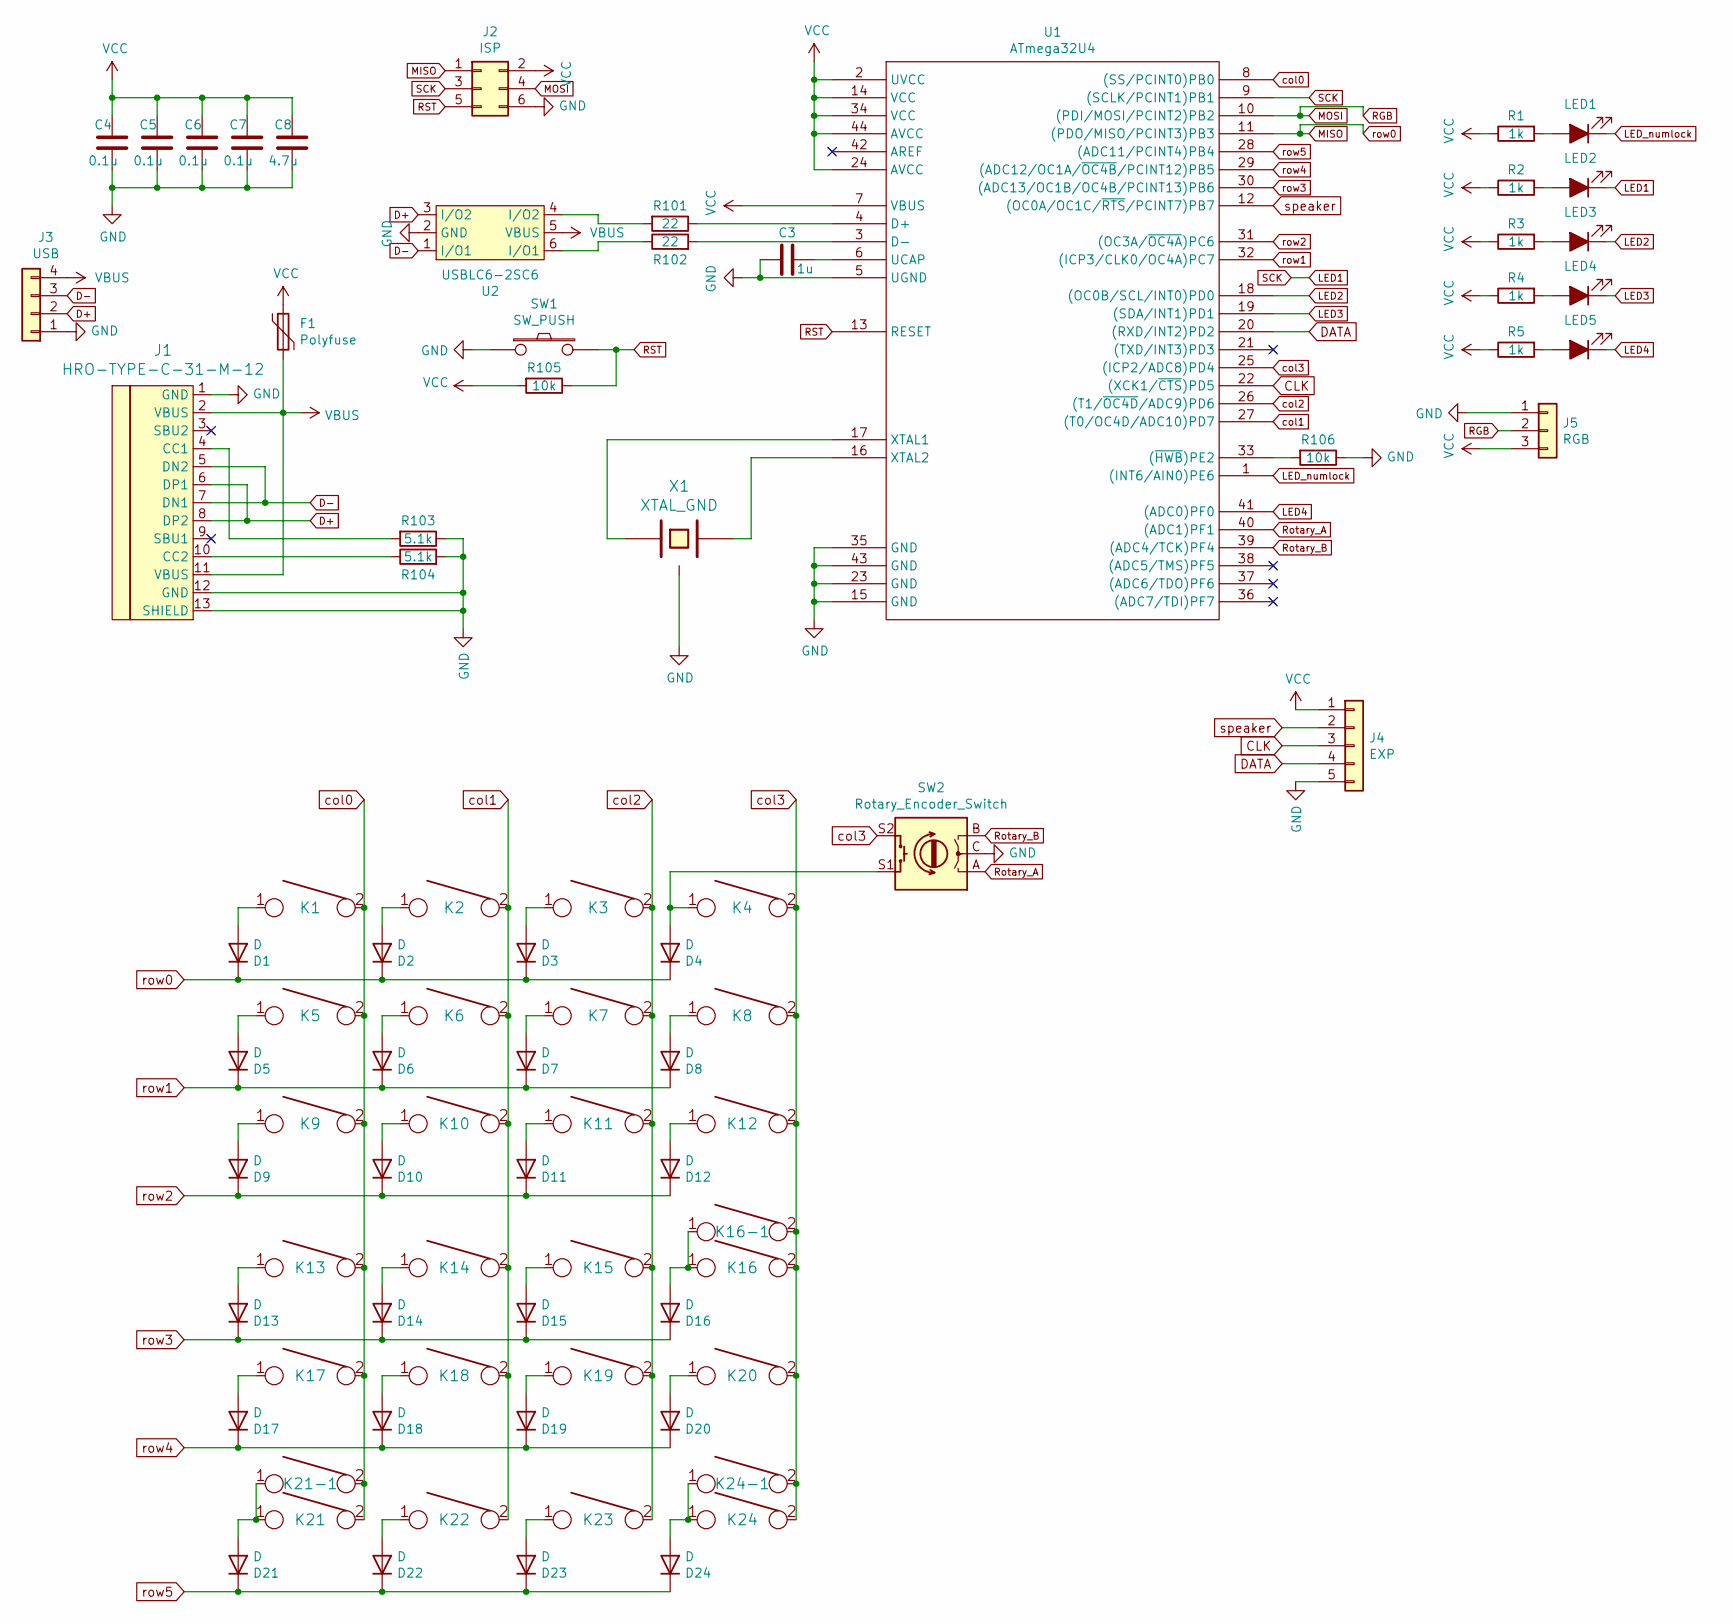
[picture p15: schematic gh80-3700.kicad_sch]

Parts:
C3: 1u; C_0805
C4, C5, C6, C7: 0.1u; C_0805
C8: 4.7u; C_0805
D1, D2, D3, D4, D5, D6, D7, D8, D9, D10, D11, D12, D13, D14, D15, D16, D17, D18, D19, D20, D21, D22, D23, D24: D; D_0805
F1: Polyfuse; R_0805
J1: HRO-TYPE-C-31-M-12
J2: ISP; isp_standard
J3: USB; USB_breakout
J4: EXP; JST_SH_SM05B-SRSS-TB_1x05-1MP_P1.00mm_Horizontal
J5: RGB; PinHeader_1x03_P2.54mm_Vertical
K1, K2, K3, K4, K5, K6, K7, K8, K9, K10, K11, K12, K13, K14, K15, K16, K17, K18, K19, K20, K21, K22, K23, K24: KEYSW; CHERRY_PLATE_100H
K16-1, K24-1: KEYSW; CHERRY_PCB_200H_V
K21-1: KEYSW; CHERRY_PCB_200H
LED1, LED2, LED3, LED4, LED5: LED_ALT; CHERRY_MX_LED
R1, R2, R3, R4, R5: 1k; R_0805
R101, R102: 22; R_0805
R103, R104: 5.1k; R_0805
R105, R106: 10k; R_0805
SW1: SW_PUSH; HRO_K2-1109DE-D4SW-01
SW2: Rotary_Encoder_Switch; RotaryEncoder_Alps_EC11
U1: ATmega32U4; ATMEGA32U4
U2: USBLC6-2SC6; Farnell 1295310
X1: XTAL_GND; Resonator_SMD_muRata_CSTNExxV-3Pin-p1.2

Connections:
CLK: J4.3, U1.22 ((XCK1/~CTS~)PD5)
D+: J1.6 (DP1), J1.8 (DP2), J3.2, U2.3 (I/O2)
D-: J1.5 (DN2), J1.7 (DN1), J3.3, U2.1 (I/O1)
DATA: J4.4, U1.20 ((RXD/INT2)PD2)
GND: C3.2, C4.1, C5.1, C6.1, C7.1, C8.1, J1.1 (GND), J1.12 (GND), J1.13 (SHIELD), J2.6, J3.1, J4.5, J5.1, R103.1, R104.2, R106.1, SW1.1, SW2.C, U1.5 (UGND), U1.15 (GND), U1.23 (GND), U1.35 (GND), U1.43 (GND), U2.2 (GND), X1.3
LED1: J2.3, LED2.1 (K), U1.9 ((SCLK/PCINT1)PB1)
LED2: LED3.1 (K), U1.18 ((OC0B/SCL/INT0)PD0)
LED3: LED4.1 (K), U1.19 ((SDA/INT1)PD1)
LED4: LED5.1 (K), U1.41 ((ADC0)PF0)
LED_numlock: LED1.1 (K), U1.1 ((INT6/AIN0)PE6)
MISO: D1.1 (K), D2.1 (K), D3.1 (K), D4.1 (K), J2.1, U1.11 ((PDO/MISO/PCINT3)PB3)
MOSI: J2.4, J5.2, U1.10 ((PDI/MOSI/PCINT2)PB2)
unnamed: C3.1, U1.6 (UCAP)
unnamed: D1.2 (A), K1.1
unnamed: D2.2 (A), K2.1
unnamed: D3.2 (A), K3.1
unnamed: D4.2 (A), K4.1, SW2.S1
unnamed: D5.2 (A), K5.1
unnamed: D6.2 (A), K6.1
unnamed: D7.2 (A), K7.1
unnamed: D8.2 (A), K8.1
unnamed: D9.2 (A), K9.1
unnamed: D10.2 (A), K10.1
unnamed: D11.2 (A), K11.1
unnamed: D12.2 (A), K12.1
unnamed: D13.2 (A), K13.1
unnamed: D14.2 (A), K14.1
unnamed: D15.2 (A), K15.1
unnamed: D16.2 (A), K16.1, K16-1.1
unnamed: D17.2 (A), K17.1
unnamed: D18.2 (A), K18.1
unnamed: D19.2 (A), K19.1
unnamed: D20.2 (A), K20.1
unnamed: D21.2 (A), K21.1, K21-1.1
unnamed: D22.2 (A), K22.1
unnamed: D23.2 (A), K23.1
unnamed: D24.2 (A), K24.1, K24-1.1
unnamed: J1.4 (CC1), R103.2
unnamed: J1.10 (CC2), R104.1
unnamed: LED1.2 (A), R1.2
unnamed: LED2.2 (A), R2.2
unnamed: LED3.2 (A), R3.2
unnamed: LED4.2 (A), R4.2
unnamed: LED5.2 (A), R5.2
unnamed: R101.1, U1.4 (D+)
unnamed: R101.2, U2.4 (I/O2)
unnamed: R102.1, U2.6 (I/O1)
unnamed: R102.2, U1.3 (D-)
unnamed: R106.2, U1.33 ((~HWB~)PE2)
unnamed: U1.16 (XTAL2), X1.2
unnamed: U1.17 (XTAL1), X1.1
RST: J2.5, R105.1, SW1.2, U1.13 (RESET)
Rotary_A: SW2.A, U1.40 ((ADC1)PF1)
Rotary_B: SW2.B, U1.39 ((ADC4/TCK)PF4)
VBUS: F1.2, J1.2 (VBUS), J1.11 (VBUS), J3.4, U2.5 (VBUS)
VCC: C4.2, C5.2, C6.2, C7.2, C8.2, F1.1, J2.2, J4.1, J5.3, R1.1, R2.1, R3.1, R4.1, R5.1, R105.2, U1.2 (UVCC), U1.7 (VBUS), U1.14 (VCC), U1.24 (AVCC), U1.34 (VCC), U1.44 (AVCC)
col0: K1.2, K5.2, K9.2, K13.2, K17.2, K21.2, K21-1.2, U1.8 ((SS/PCINT0)PB0)
col1: K2.2, K6.2, K10.2, K14.2, K18.2, K22.2, U1.27 ((T0/OC4D/ADC10)PD7)
col2: K3.2, K7.2, K11.2, K15.2, K19.2, K23.2, U1.26 ((T1/~OC4D~/ADC9)PD6)
col3: K4.2, K8.2, K12.2, K16.2, K16-1.2, K20.2, K24.2, K24-1.2, SW2.S2, U1.25 ((ICP2/ADC8)PD4)
row1: D5.1 (K), D6.1 (K), D7.1 (K), D8.1 (K), U1.32 ((ICP3/CLK0/OC4A)PC7)
row2: D9.1 (K), D10.1 (K), D11.1 (K), D12.1 (K), U1.31 ((OC3A/~OC4A~)PC6)
row3: D13.1 (K), D14.1 (K), D15.1 (K), D16.1 (K), U1.30 ((ADC13/OC1B/OC4B/PCINT13)PB6)
row4: D17.1 (K), D18.1 (K), D19.1 (K), D20.1 (K), U1.29 ((ADC12/OC1A/~OC4B~/PCINT12)PB5)
row5: D21.1 (K), D22.1 (K), D23.1 (K), D24.1 (K), U1.28 ((ADC11/PCINT4)PB4)
speaker: J4.2, U1.12 ((OC0A/OC1C/~RTS~/PCINT7)PB7)

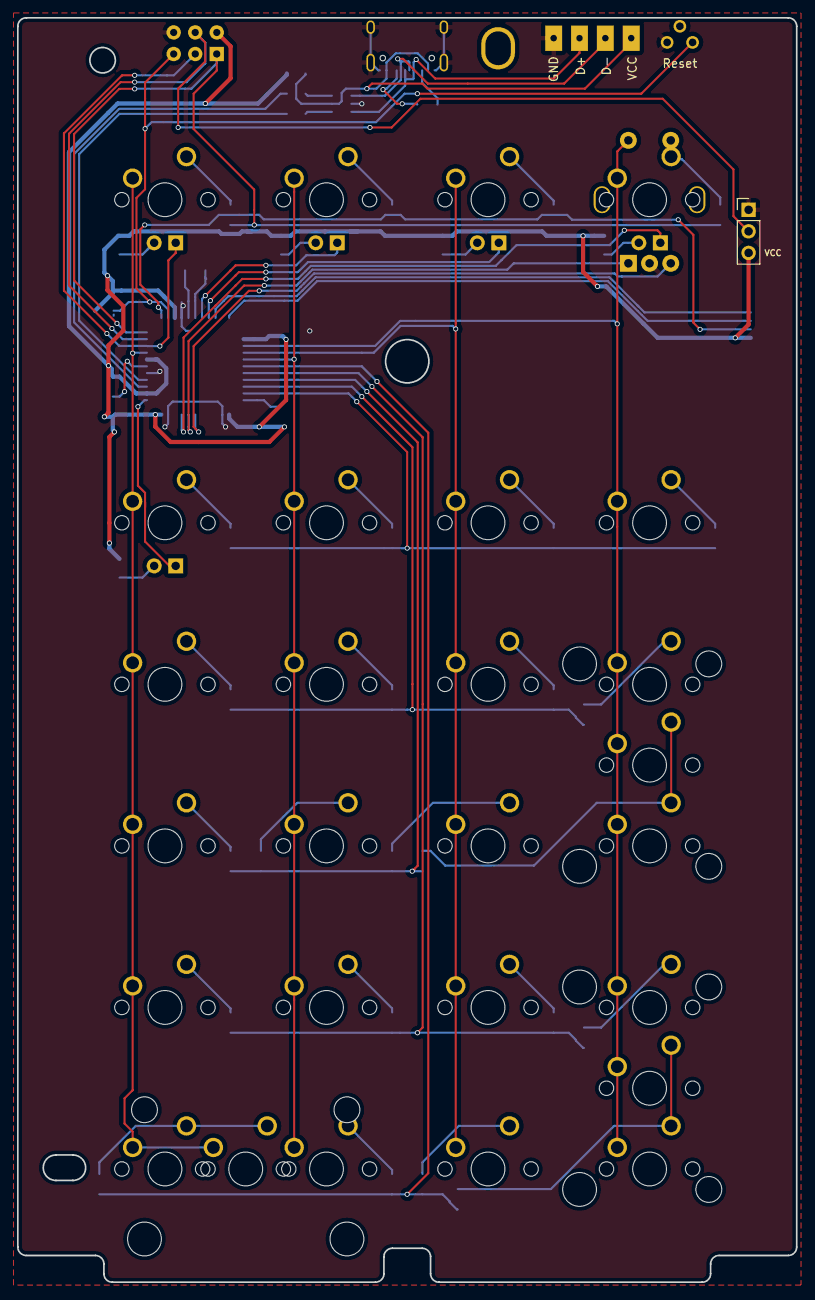
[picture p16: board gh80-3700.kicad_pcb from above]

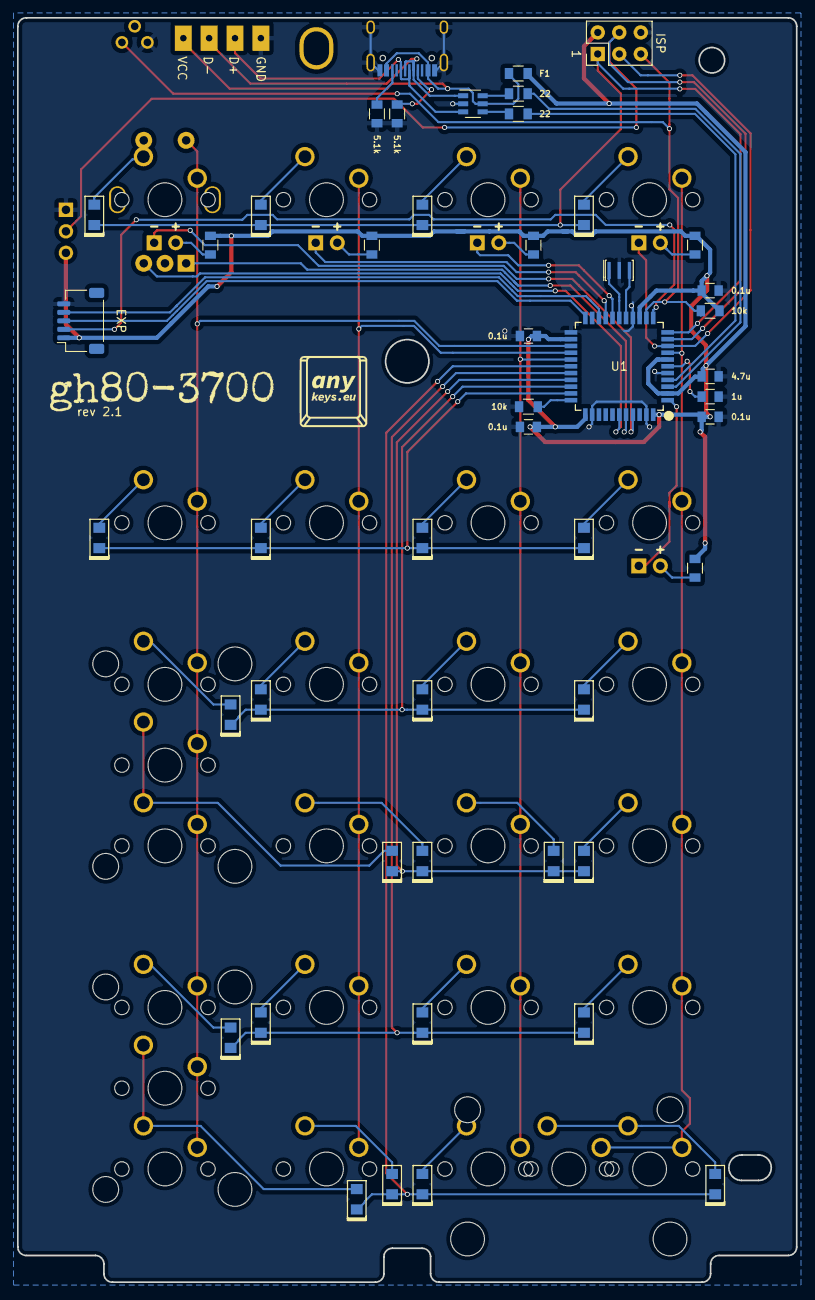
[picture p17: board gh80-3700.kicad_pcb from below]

Board: 2 copper layers, 91.8 x 149.1 mm, 84 parts (48 on the bottom side), 66 nets.

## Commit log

2020-09-26 Add website logo/remove maartenwut
    [daughterboard.kicad_pcb, daughterboard.kicad_sch, daugtherboard.kicad_pcb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]
2020-10-01 Add 3d printable case
    [bottom.stl, case.f3z, top.stl]
2020-10-03 add gh80-3003 jlcpcb fab remix
    [gh80-3003-B_Cu.gbr, gh80-3003-B_Mask.gbr, gh80-3003-B_SilkS.gbr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]
2021-04-03 Upload GH80-3003 plate
    [gh80-3003-ansi.dxf, gh80-3003-iso.dxf, plate.FCStd]
